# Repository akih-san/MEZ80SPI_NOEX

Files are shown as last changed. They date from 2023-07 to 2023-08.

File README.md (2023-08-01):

# MEZ80SPI_NOEX
MEZ80SPI_NOEX_1
MEZ80SPI_NOEX本体<br>
<br>
MEZ80SPI_NOEX_1
EMUZ80にMEZ80SPI_NOEXを装着<br>
<br>
MEZ80SPI_NOEX_2
さらに、μSDカードを装着<br>
<br>
<br>
EMUZ80は、電脳伝説さん(@vintagechips)によって公開された最小構成で動くレトロな<br>
シングルボードコンピュータです。<br>
<br>
SuperMEZ80は、奥江 聡(@S_Okue)さんによって公開された、EMUZ80上で動くアドオン<br>
ボードです。Z80とRAMをアドオンボードで動作させ、64Kバイトのメモリ空間と、最大<br>
16MHzでZ80を動かすことが可能となっています。<br>
<br>
Hanya Zou(@hanyazou)さんによって公開された、SuperMEZ80をベースにμSDカードを実装した<br>
モデルでは、CP/M 2.2が動作します。<br>
さらに、512KバイトメモリとCP/M 3.0が動作するアドオンボードも開発されています。<br>
<br>
<br>
今回、Hanya Zou(@hanyazou)さんのCP/M 2.2が動作するSuperMEZ80をシュリンクしたモデル<br>
MEZ80SPI_NOEXを公開いたします。(NOEX：NO EXpanded memory model)<br>
<br>
部品に表面実装チップを用い、基板をシュリンクしたモデルになります。<br>
SuperMEZ80より小さい基板上で64Kバイト CP/M 2.2が動作します。<br>
<br>
（公開データ）<br>
<br>
１．ガーバーデータ<br>
２．PIC18F47Q84用のファームウェア<br>
３．CP/M用のディスクイメージ<br>
<br>
基板に1番ピンのシルクを忘れたので、印を付けた画像を張り付けておきます。<br>
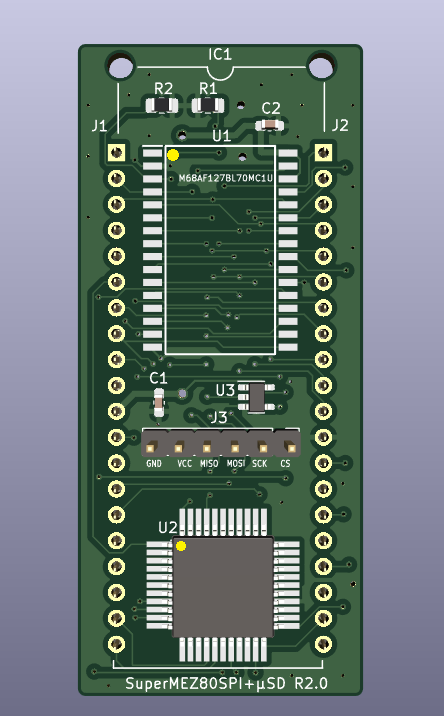
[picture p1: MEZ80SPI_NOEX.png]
MEZ80SPI_NOEX_3


ファームウェア、CP/M用ディスクイメージの詳細については、<br>
Hanya Zou(@hanyazou)さんの公開データを参照してください。<br>
<br>
<br>
参考）<br>
<br>
電脳伝説 - EMUZ80が完成  
https://vintagechips.wordpress.com/2022/03/05/emuz80_reference<br>
<br>
EMUZ80専用プリント基板 - オレンジピコショップ<br>
https://store.shopping.yahoo.co.jp/orangepicoshop/pico-a-051.html<br>
<br>
奥江 聡(@S_Okue) - SuperMEZ80<br>
https://github.com/satoshiokue/SuperMEZ80<br>
<br>
Hanya Zou(@hanyazou) - CP/M 2.2 for SuperMEZ80<br>
https://github.com/hanyazou/SuperMEZ80<br>
メザニンボード<br>
https://github.com/hanyazou/SuperMEZ80-SPI<br>
<br>
<br>
https://twitter.com/akih_san<br>

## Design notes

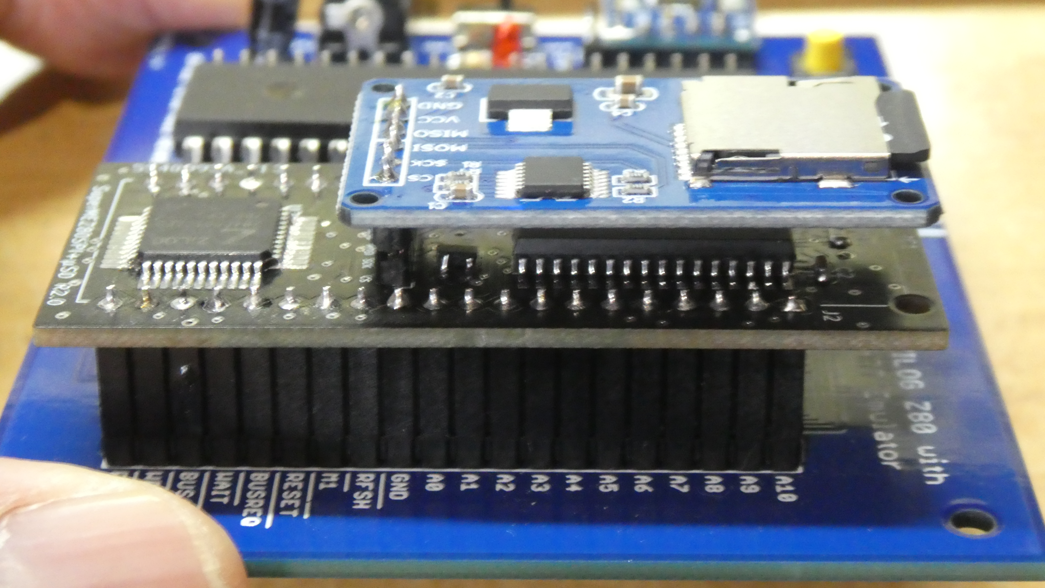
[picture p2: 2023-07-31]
Photos/F2Ni_ogagAAgfKo.jpg

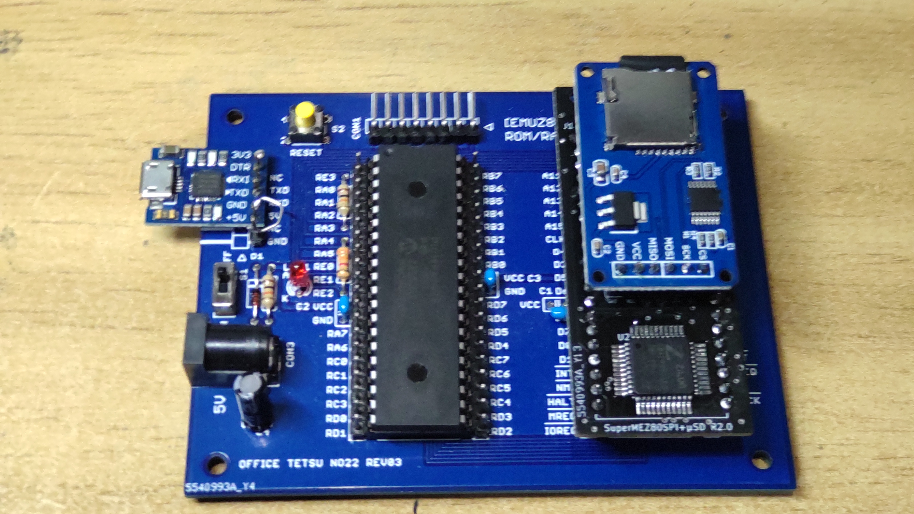
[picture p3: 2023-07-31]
Photos/F2Nix4AbkAAkcxB.jpg

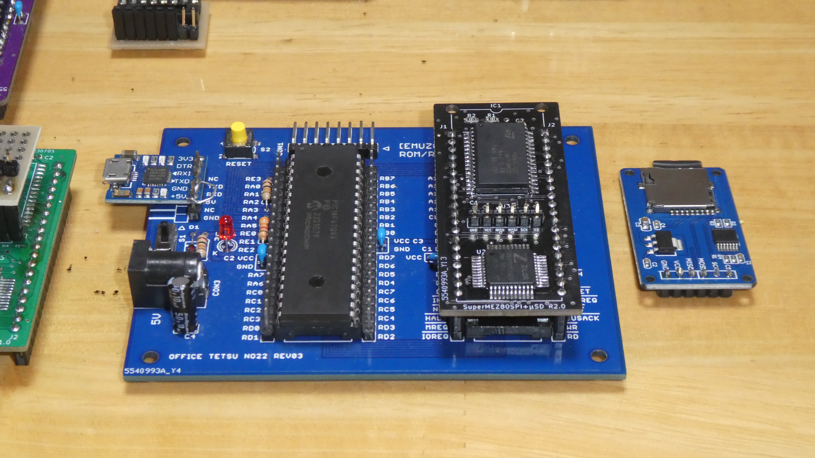
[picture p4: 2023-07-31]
Photos/F2PZdRjbYAAt2YP.jpg

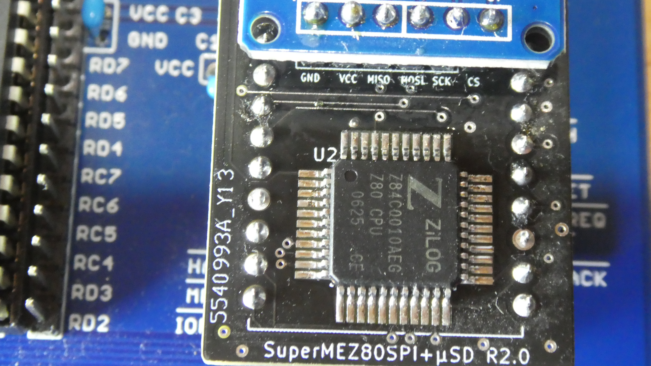
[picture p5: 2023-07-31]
Photos/F2Ni9WsbwAACOTO.jpg

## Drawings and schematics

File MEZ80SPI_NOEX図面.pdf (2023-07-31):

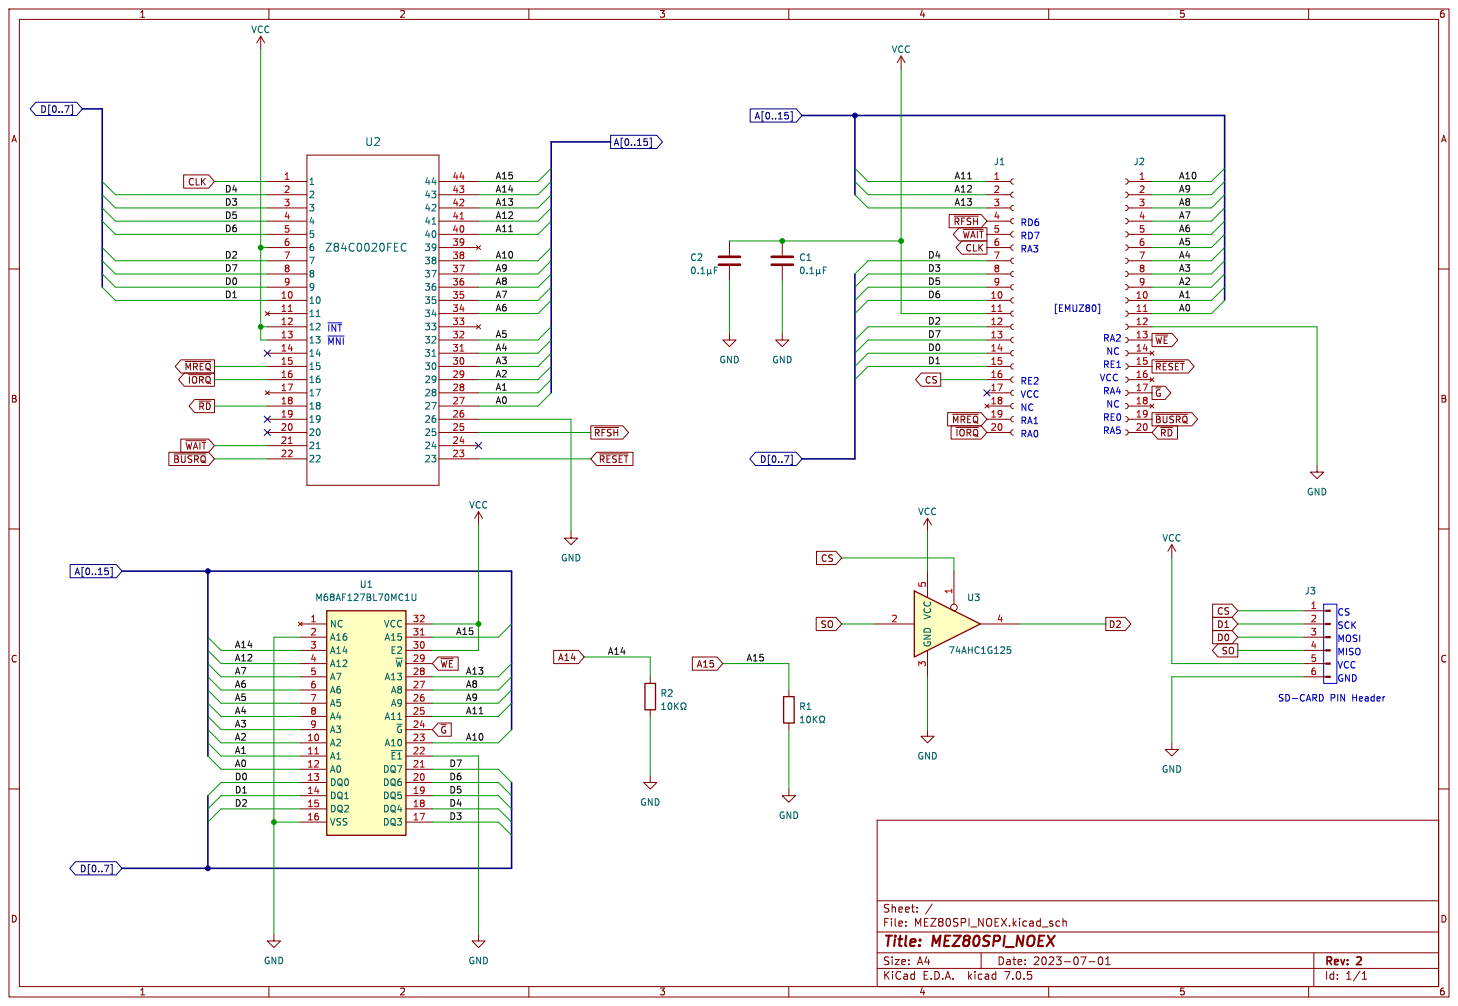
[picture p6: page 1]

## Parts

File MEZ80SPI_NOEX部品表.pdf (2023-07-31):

MEZ80SPI_NOEX | （部品表）
項目 | 部品番号 | 部品名 | 値 | 個数 | 部品番号等
1 | C1, C2 | セラミックコンデンサー | 0.1μF | 2 | チップ積層セラミックコンデンサー ０．１μＦ５０Ｖ Ｆ １６０８
2 | R1, R2 | 抵抗 | 10KΩ | 2 | 金属皮膜チップ抵抗器 ２０１２ １／８Ｗ１０ｋΩ
3 | μSD-CARD-module | μSD-CARD module | - | 1 | SPIインターフェース Arduino Raspberry Pi用μSD card module：AMAZON
4 | J1, J2 | EMUZ80接続用ソケット | - | 2 | ソケット1×20 （20P) 2.54mmピッチ
5 | J3 | SD-CARD PIN Header | - | 1 | ピンヘッダ1×6 （6P）2.54mmピッチ
6 | U1 | M68AF127B | - | 1 | ＳＲＡＭ １Ｍｂ Ｍ６８ＡＦ１２７Ｂ(SOP-32 1.27mmピッチ)：秋月電子通商
7 | U2 | Z84C0010FEC（相当品） | - | 1 | Z80CPU TQFP-44 Z84C0010FEC又はZ84C0010AEG（6MHz以上の相当品）
8 | U3 | 74AHC1G125 | - | 1 | SMDタイプ ３ステートバッファ ７４ＡＨＣ１Ｇ１２５Ｗ５：秋月電子通商
